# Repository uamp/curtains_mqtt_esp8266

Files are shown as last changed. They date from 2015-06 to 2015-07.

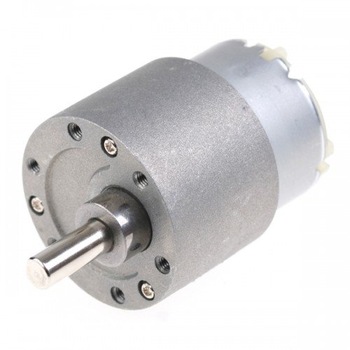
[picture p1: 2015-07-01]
hardware/mini-12v-dc-60-rpm-gear-box-micor-electric-dc-motor-high-torque-and-low-noise-ks5068_809356.jpg

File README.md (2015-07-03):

# Curtain Controller

Curtain controller using ESP8266, nodemcu and LUA script.  Primarily designed for OpenHAB, but will work with any MQTT based home automation software

## Features
* Controls curtains using a bi-directional DC motor (hooked up to H-bridge, L293D chip).  
* Uses a reed switch (attached to the lazy pulley) to count number or revolutions to determine curtain position.
* Has timeout if limit of travel reached and no reed contact seen (ie lazy pulley has stopped/jammed).
* Also has an LDR hooked up to the ADC pin and posts light level to the MQTT server.
* Manual switch that can move curtains up/down (and then posts to the MQTT server to call complete)
* WIFI reconnection and MQTT reconnection automatically.
* Compatible with any home automation software that uses MQTT (I use openhab, but any could be used)

## Software
### MQTT Topics
#### Listens to
* home/curtains1/out/init - sets the initial state "UP" or "DOWN" (command output used by openhab)
* home/curtains1/out - looks for "UP" or "DOWN" to drive the motor in correct direction (this links in with openhab command outputs)
* home/curtains1/out/vars/motor_reverse - "true" or "false" initial setting to change motor direction if needed
* home/curtains1/out/vars/reed_clicks - number of pulley revolutions required to open/close curtains
* home/curtains1/out/vars/emergency_stop - timeout (ms) if no pulse seen from the reed-switch from the lazy pulley.  If there is no reed switch installed at all, then set this to the total time required to open (or close) the curtains - the motor will just run for that time period

#### Outputs to
* home/curtains/in - position of curtains after move is successful
* home/curtains/in/light_level - direct ADC read (0-1024)

### Notes

_COMPILE:_ mqtt.lua, wifi.lua and motorfunctions.lua all need to be byte compiled to .lc to work.  ESPlorer (or others) can handle this with ease.

Enter your SSID and MQTT server details and edit the pin definitions as necessary.

On initial startup it doesn't know what position the curtains are in.  This can be combatted in two ways: 
- Write to /out/init topic to tell it it's position. 
- Send a command to move - it will assume on the first move it gets you are aware of it's initial position, so will obey blindly.  Subsequent commands will only be actioned if it is the correct place to begin with (ie, it wont try to open if already open)

## Hardware
### 3D Design/print

Hardware folder contains STL files for 3D printing for:
* Driven pulley (motor mount, and pulley with key for motor) - fits common 12v high torque motor found on ebay (picture found in the hardware folder for reference)
* Lazy pulley (mount, pulley, and end cap) - to attach at the non-working end of the curtain rail
* Lazy pulley with reed switch - allows for embeded reed switch to crudely detect rotational position

### Circuit

Circuit folder contains schematic and bread board design. It also includes Fritzing file if you want to play/edit the circuit. No PCB layout as yet as mine ended up being built on vero board.  However, this can be made from the fritzing file.

Note, the motor needs 12v, but the ESP needs 3.3v.  As it needs 700mA, best not to use a linear regulator to drop the voltage from 12v as it will get very hot.  I use a step down / buck converter which is bulkier, but more efficient.  You'll see the circuit leaves this blank for you to power as you like.

The SPDT switch needs to be a momentary switch (unlike the breadboard image) - just flick it one way or tother to move initiate curtain move.

### Pins

* H-bridge: motor a,  motor b, and motor en
* Reed switch: connect between pin and ground (uses internal pullup and interrupt routine with debouncing)
* Manual switch: SPDT: Double throw.  Ie, put common pin to ground, and either "throw" to 'swup' and 'swdown' pins on the esp respectively.  Again, internal pullup is used.
* ADC pin: Have 330/150ohm voltage dividor to bring 3.3v down to 1.1v (max reading on ESP ADC pin) then further divided that with LDR and POT to vary light dependant voltage between 0 and 1.1v.  This raw value is then put over MQTT.  A back end automation server (in my case openhab) uses this value in conjuction with knowledge of sunrise/sunset to determine if curtains should be up/down

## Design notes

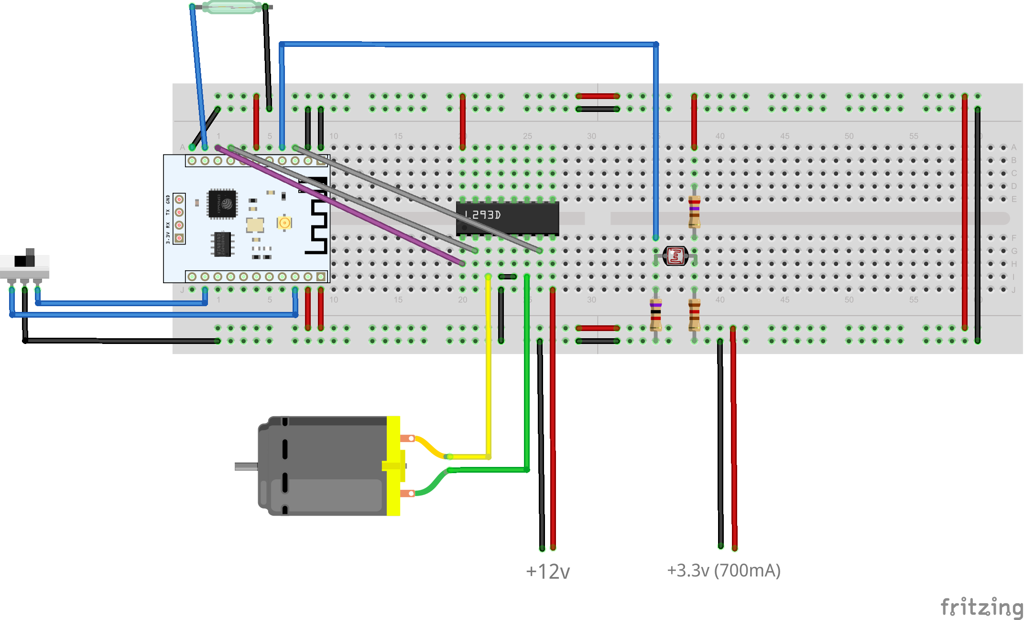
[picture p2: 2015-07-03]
hardware/circuit/esp8266_curtains_bb.png

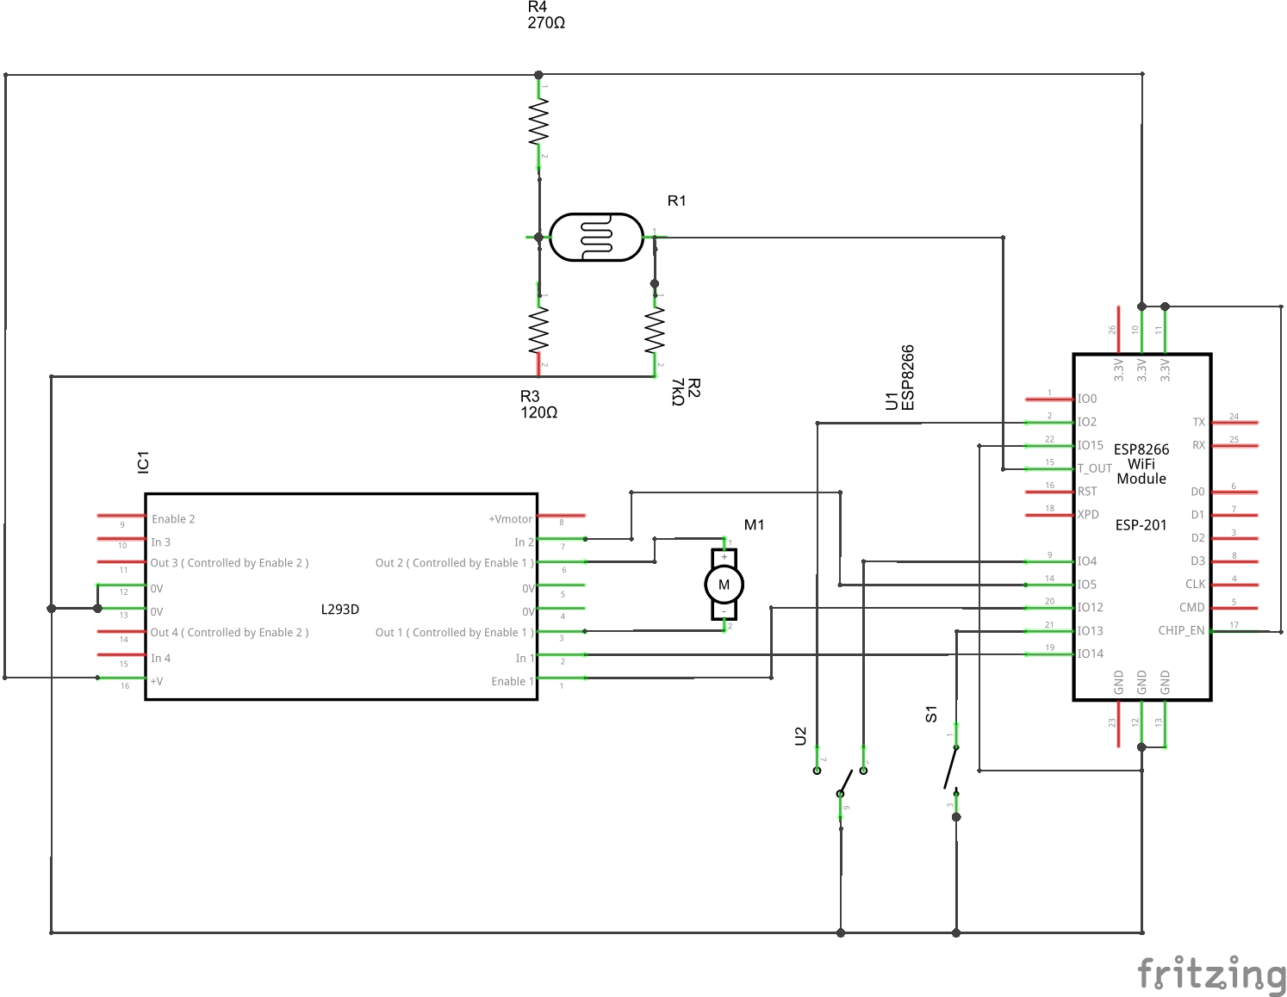
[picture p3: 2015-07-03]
hardware/circuit/esp8266_curtains_schem.png

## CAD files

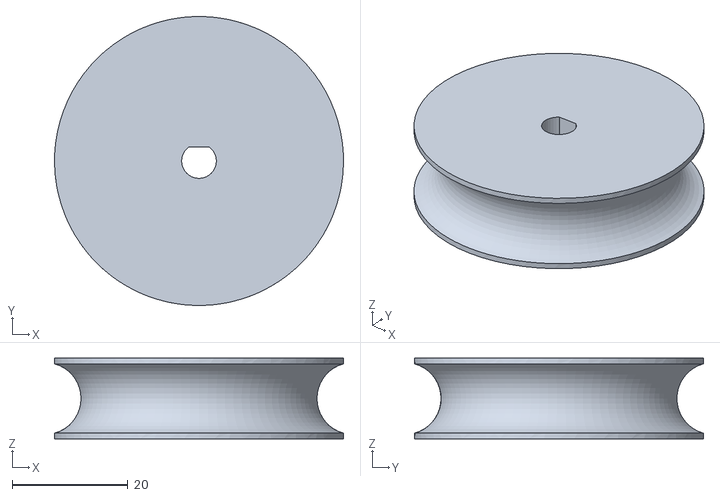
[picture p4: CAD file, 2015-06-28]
hardware/driven pulley assembly/pulley with key.STL
50.0 x 50.0 x 14.0

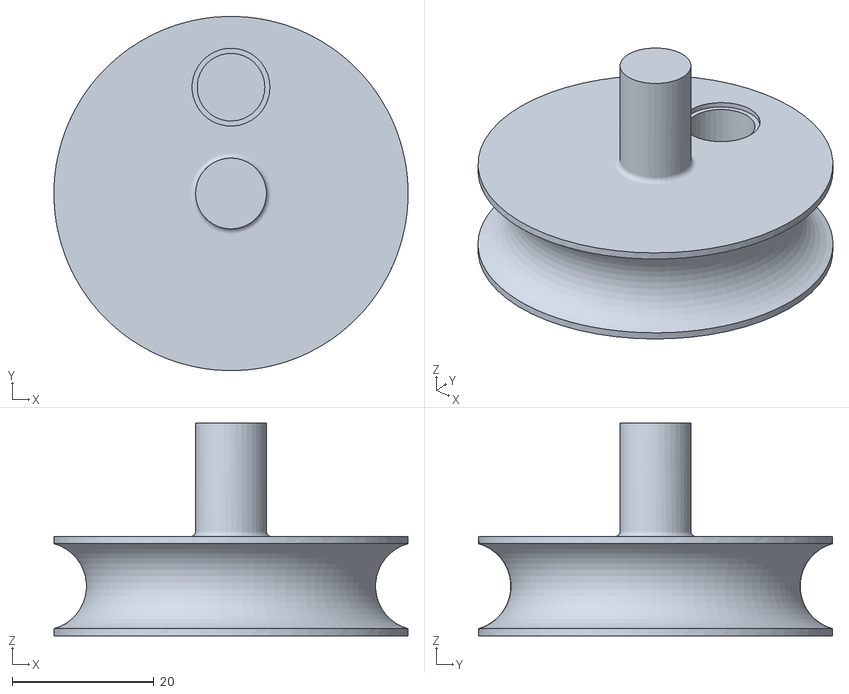
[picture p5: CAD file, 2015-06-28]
hardware/lazy pulley assembly with reed switch fitting/pulley2.STL
50.0 x 50.0 x 30.0

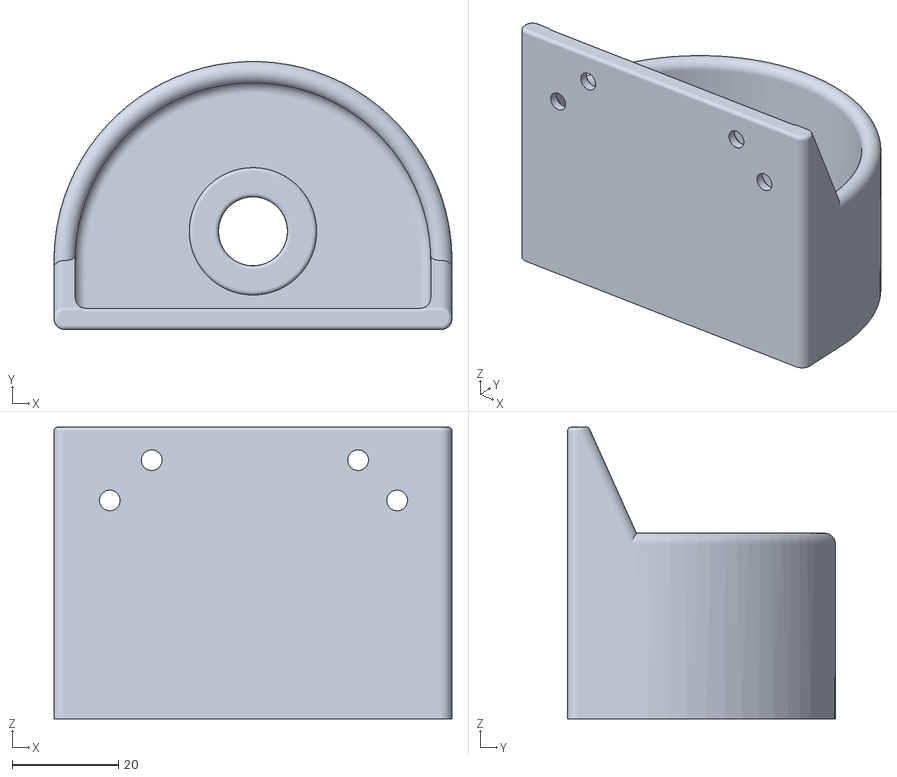
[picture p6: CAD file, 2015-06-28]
hardware/lazy pulley assembly/pulleymount2.STL
75.0 x 50.5 x 55.0

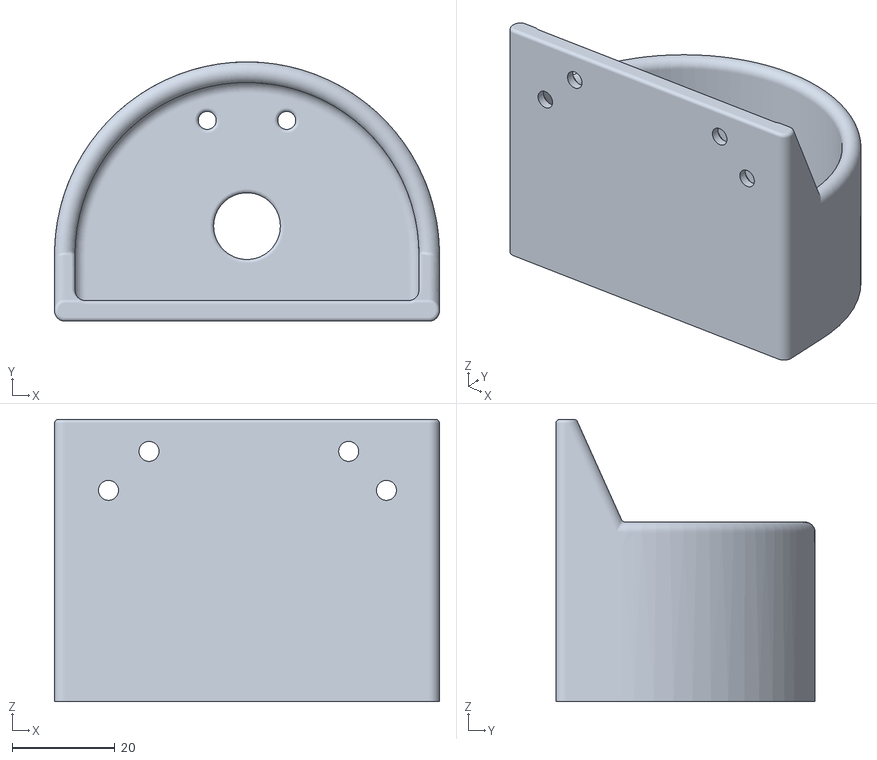
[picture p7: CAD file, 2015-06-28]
hardware/driven pulley assembly/pulleymount.STL
75.0 x 50.5 x 55.0

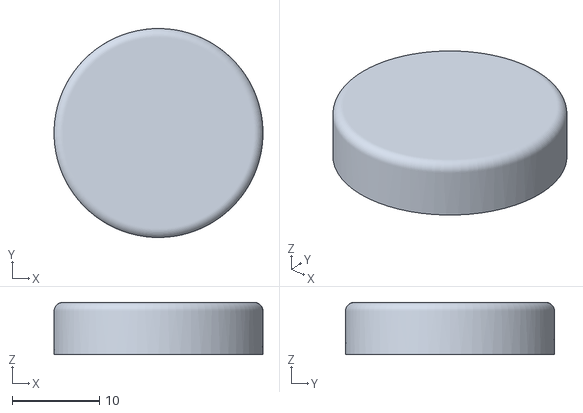
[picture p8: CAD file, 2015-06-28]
hardware/lazy pulley assembly/pulley end cap.STL
24.0 x 24.0 x 6.00

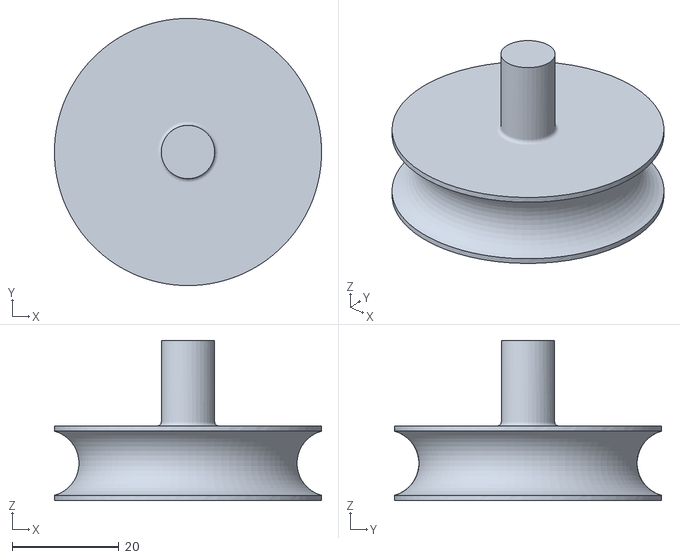
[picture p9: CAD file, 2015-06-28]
hardware/lazy pulley assembly/pulley.STL
50.0 x 50.0 x 30.0

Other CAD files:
hardware/lazy pulley assembly with reed switch fitting/pulleymount3.STL

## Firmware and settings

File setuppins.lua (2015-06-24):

motor_en=6 --io12 (blue on dev)
motor_a=5 -- io14 (white on dev)
motor_b=1 -- io5 (buzzer on dev)
sw_up=4 --io2 (s3 on dev)
sw_dn=2 --io4 (DHT11 on dev)
sw_reed=7 --io13 (green on dev)
--sw_reed=3 --sw2 on dev

gpio.mode(motor_en,gpio.OUTPUT)
gpio.write(motor_en, gpio.LOW)
gpio.mode(motor_a,gpio.OUTPUT)
gpio.write(motor_a, gpio.LOW)
gpio.mode(motor_b,gpio.OUTPUT)
gpio.write(motor_b, gpio.LOW)

gpio.mode(sw_up,gpio.INPUT,gpio.PULLUP)
gpio.mode(sw_dn,gpio.INPUT,gpio.PULLUP)

current_position="UNKNOWN" --in due course will change the way this activates
if(gpio.read(sw_up)==0) then
    current_position="UP"
end
if(gpio.read(sw_dn)==0) then
    current_position="DOWN"
end

gpio.mode(sw_up,gpio.INT,gpio.PULLUP)
gpio.mode(sw_dn,gpio.INT,gpio.PULLUP)

gpio.mode(sw_reed,gpio.INT,gpio.PULLUP)

current_click=0
currently_moving=false

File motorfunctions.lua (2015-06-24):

--NEEDS COMPILING

function motor_dir1()
       gpio.write(motor_en, gpio.LOW)
       gpio.write(motor_a, gpio.LOW)
       gpio.write(motor_b, gpio.HIGH)
       gpio.write(motor_en, gpio.HIGH)
       currently_moving=true
end

function  motor_dir2()
       gpio.write(motor_en, gpio.LOW)
       gpio.write(motor_b, gpio.LOW)
       gpio.write(motor_a, gpio.HIGH)
       gpio.write(motor_en, gpio.HIGH)
       currently_moving=true
end

function  motor_stop()
       current_click=0
       gpio.write(motor_en, gpio.LOW)
       gpio.write(motor_b, gpio.LOW)
       gpio.write(motor_a, gpio.LOW)
       currently_moving=false
       m:publish("home/curtains1/in",current_position,0,0, function(conn) print("sent") end)
end

function curtains_up()
        if ((current_position~="UP") and (currently_moving==false)) then
            current_click=0
            if (motor_reverse) then
                motor_dir1()
            else
                motor_dir2()
            end
            tmr.alarm( 0, emergency_stop_time, 0, motor_stop)
            current_position="UP"
        end
end

function curtains_down()
        if ((current_position~="DOWN") and (currently_moving==false)) then
            current_click=0
            if (motor_reverse) then
                motor_dir2()
            else
                motor_dir1()
            end
            tmr.alarm( 0, emergency_stop_time, 0, motor_stop)
            current_position="DOWN"
        end
end

function reed_count()
    --make sure it is definately LOW
    if (gpio.read(sw_reed)==gpio.HIGH) then return end 
    current_click=current_click+1
    print(current_click)
    if (current_click>reed_clicks) then
        motor_stop()
    end
    tmr.stop(0)
    tmr.alarm( 0, emergency_stop_time, 0, motor_stop)
end

function debounce()
    tmr.stop(2)
    tmr.alarm( 2, 20, 0, reed_count)
end

gpio.trig(sw_up, 'down', curtains_up)
gpio.trig(sw_dn, 'down', curtains_down)
gpio.trig(sw_reed,'down', debounce)

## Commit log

2015-06-28 Changes to be committed: new file: hardware/pulley end cap.STL new file: hardware/pulley.STL new file: hardware/pulley2.STL new file: hardware/pulleymount.STL new file: hardware/pulleymount2.STL new 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
    [pulley end cap.STL, pulley.STL, pulley2.STL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]
2015-06-28 Hardware
    Init commit
    [pulley with key.STL]
2015-06-28 Initial hardware commit
    [pulley end cap.STL, pulley with key.STL, pulley.STL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]
2015-07-01 new file: mini-13v-dc-60-rpm-gear-box-micor-electric-dc-motor-high-torque-and-low-noise-ks5068_809356.jpg
2015-07-03 new file: circuit/esp8266_curtains.fzz new file: circuit/esp8266_curtains_bb.png new file: circuit/esp8266_curtains_schem.png
    [esp8266_curtains.fzz]
2015-07-03 modified: circuit/esp8266_curtains.fzz modified: circuit/esp8266_curtains_bb.png
    [esp8266_curtains.fzz]
